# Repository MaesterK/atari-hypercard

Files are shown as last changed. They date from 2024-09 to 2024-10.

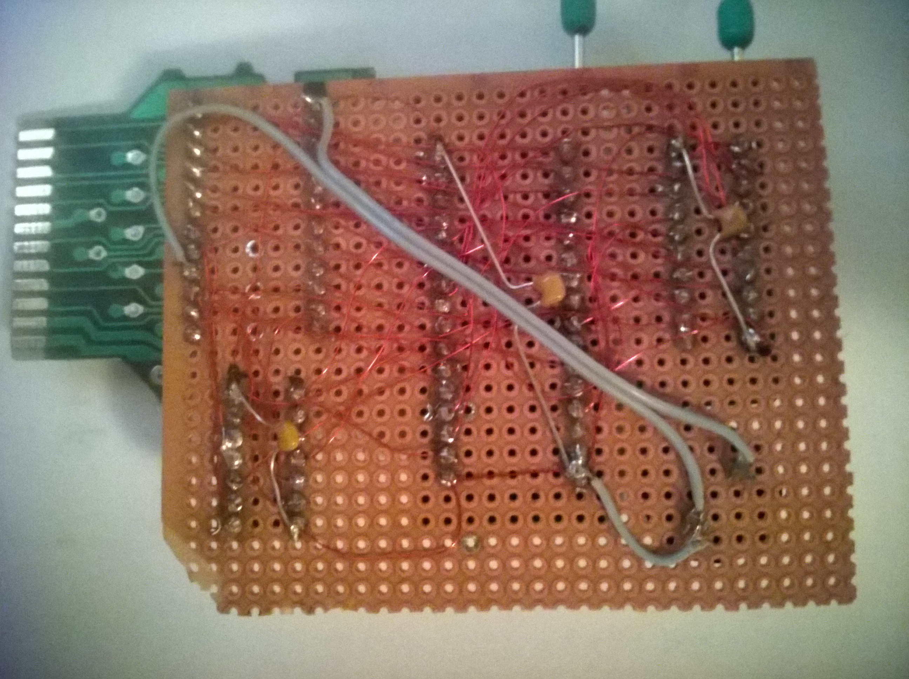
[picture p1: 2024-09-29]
pictures/lochraster_back.jpg

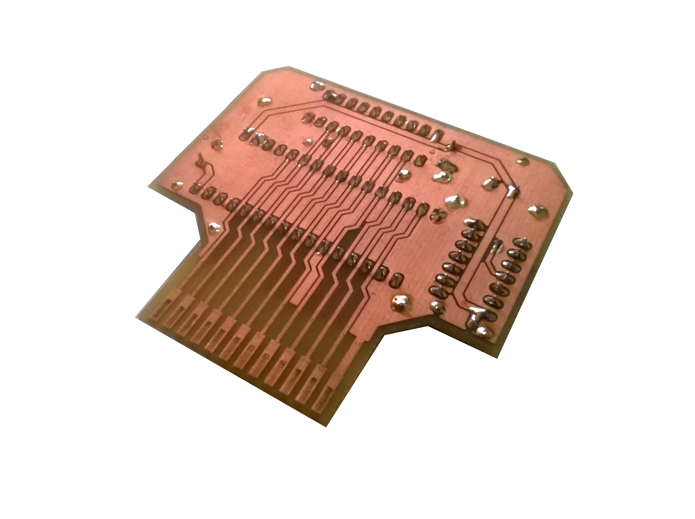
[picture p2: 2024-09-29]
pictures/pcb_rs.png

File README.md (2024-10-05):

Atari VCS / 2600 Supercard with menu implemented for atari itself creating text based menu on the fly.
Uses programmable logic ic (GAL) as latch and nand chip to select and switch between images via adress bus. 
Works only with early ("dumb") images.

The assembly code for the menu build using DASM and the framework (mainly the definitions from vcs.h) from SvOlli's atari 2600 workshop (https://svolli.org/atari2600/)

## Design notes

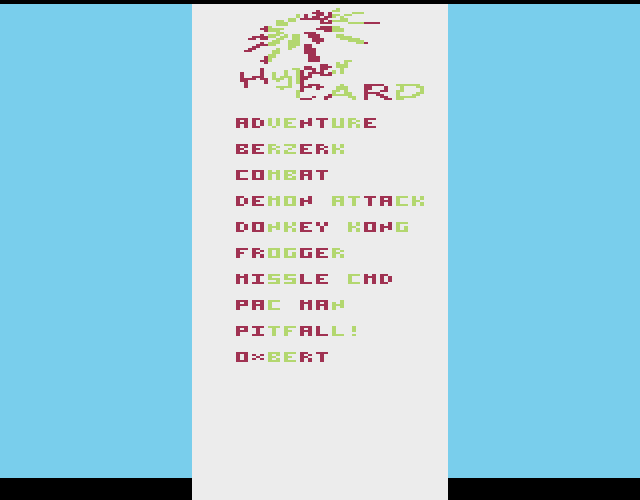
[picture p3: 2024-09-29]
pictures/menue2.png

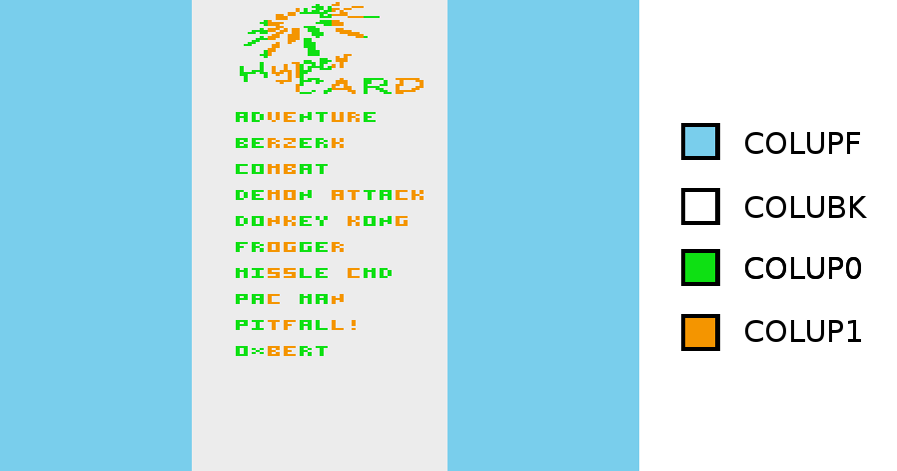
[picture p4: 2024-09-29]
pictures/menueexplained.png

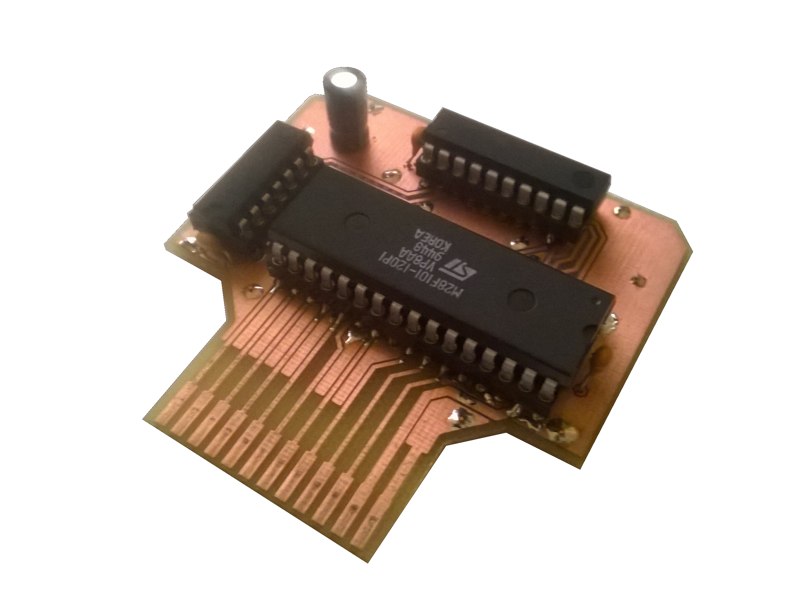
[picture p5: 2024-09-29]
pictures/pcb_vs.png

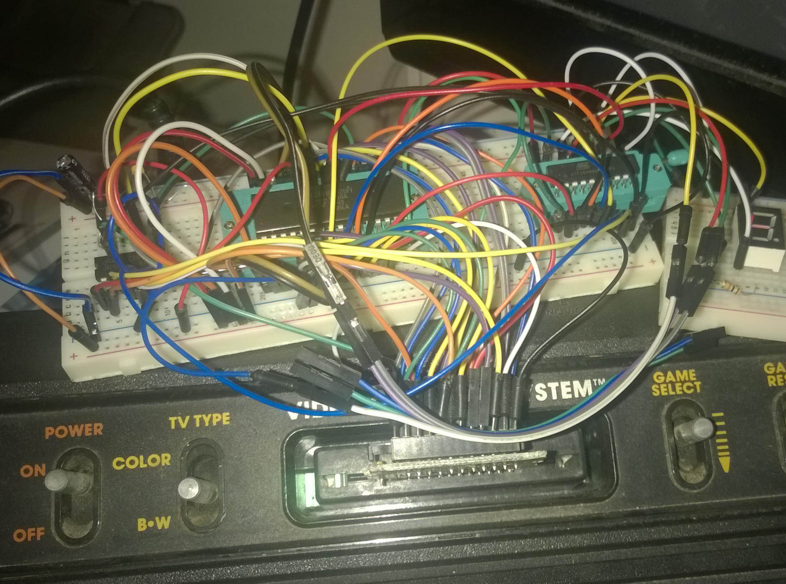
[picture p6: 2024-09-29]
pictures/breadboard_complete_small.jpg

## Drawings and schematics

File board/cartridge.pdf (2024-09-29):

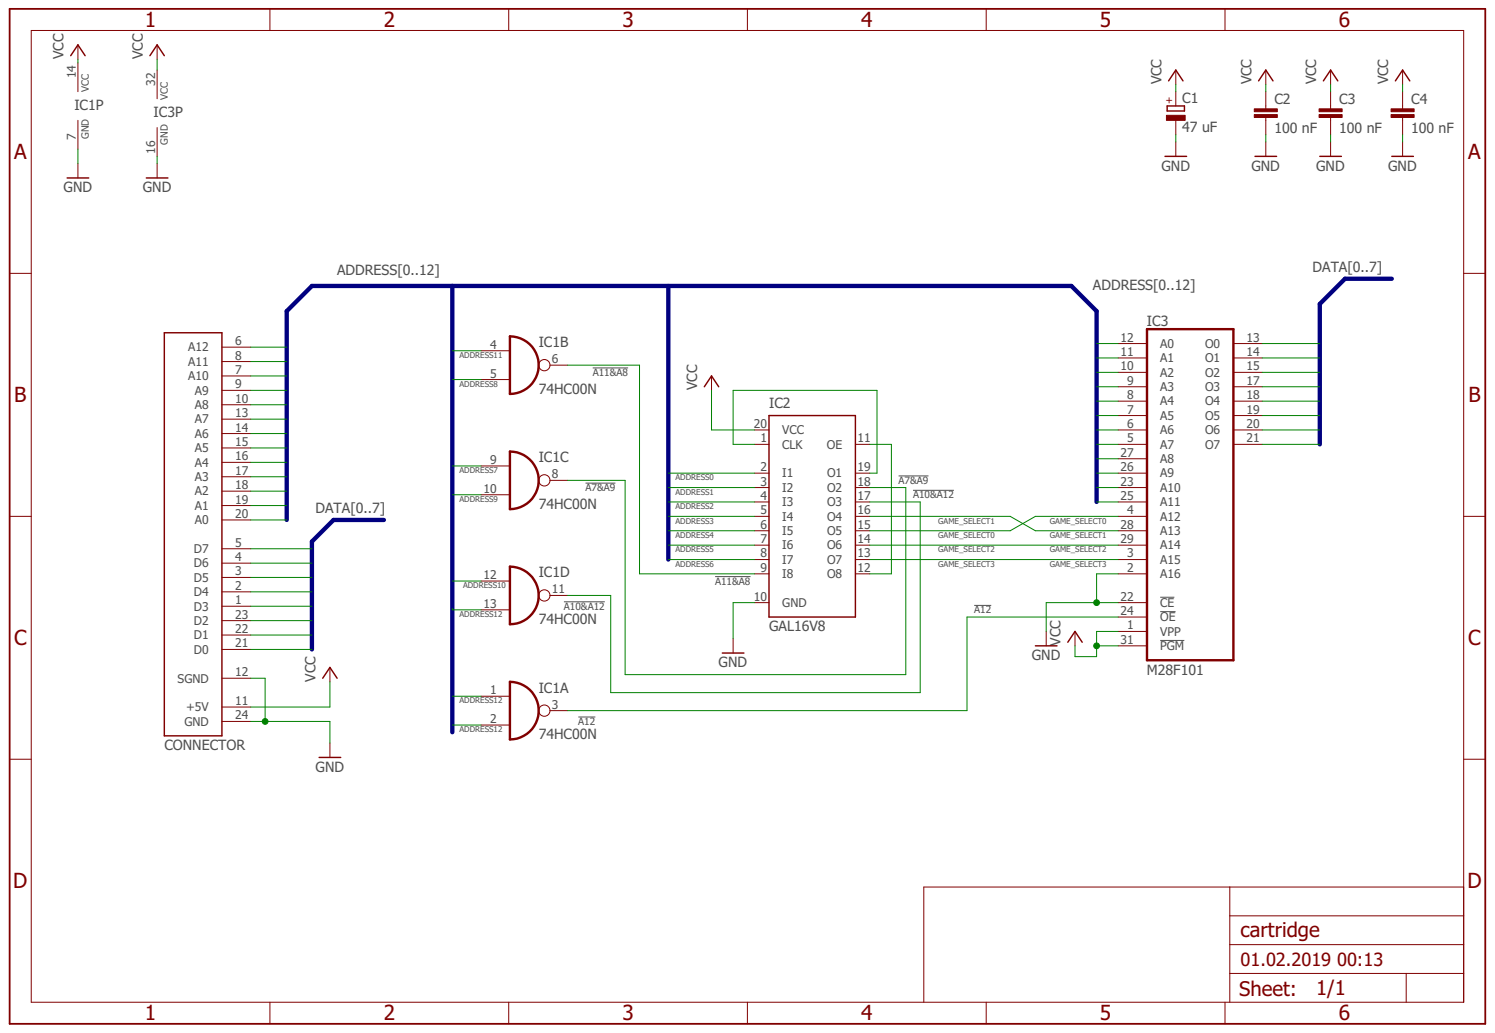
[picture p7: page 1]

IC3P ADDRESS DATA[0..7] [0..12]

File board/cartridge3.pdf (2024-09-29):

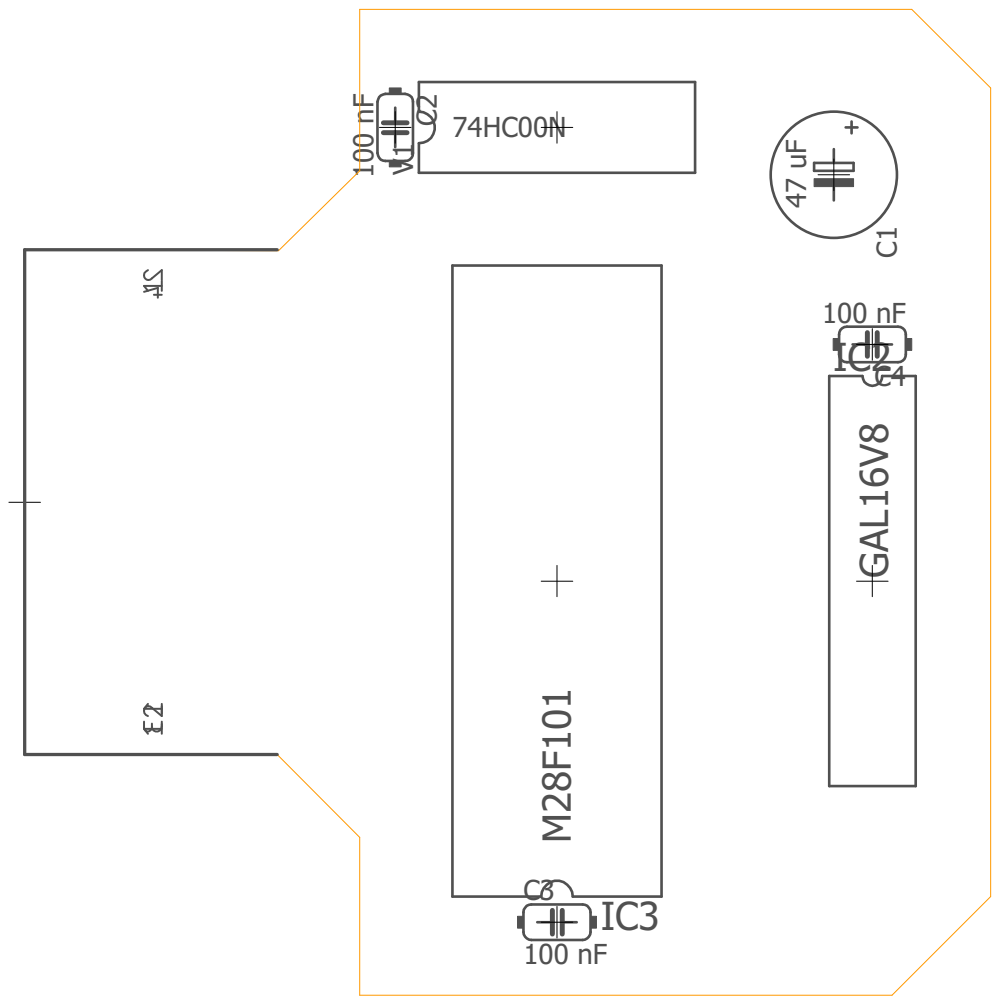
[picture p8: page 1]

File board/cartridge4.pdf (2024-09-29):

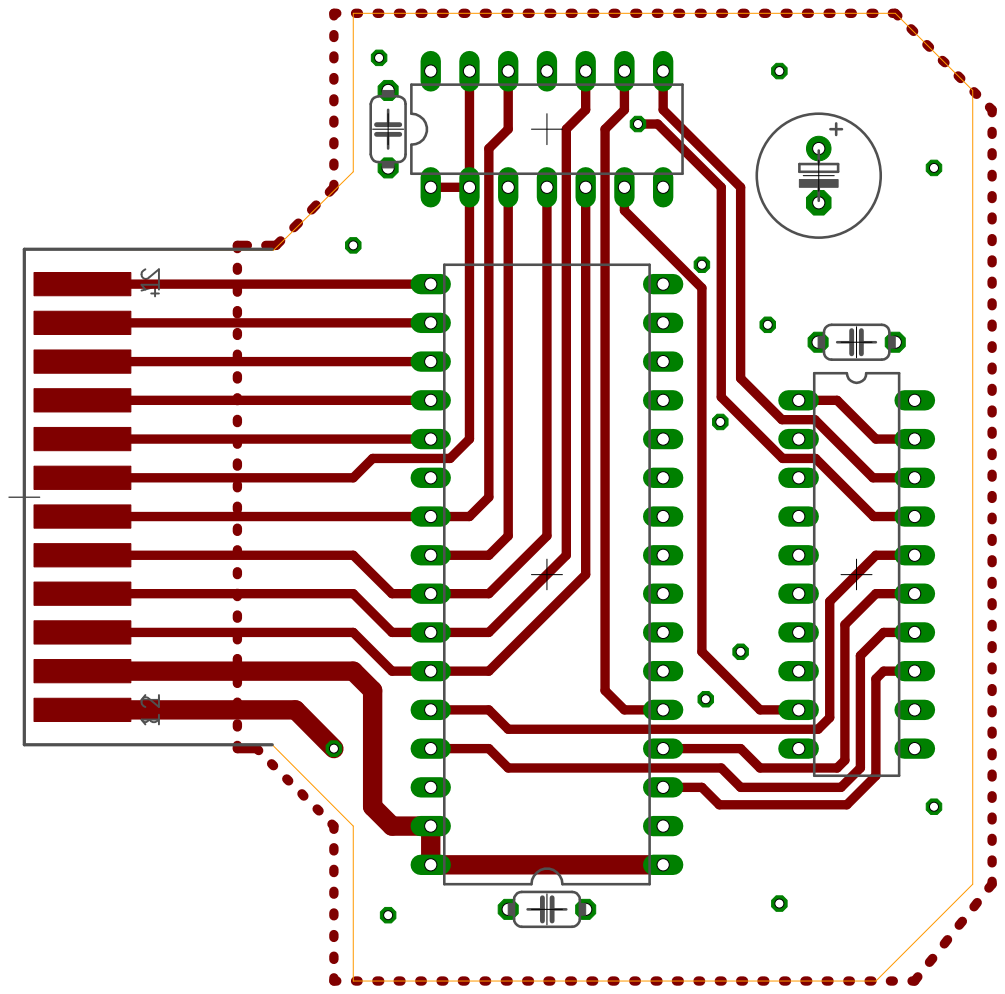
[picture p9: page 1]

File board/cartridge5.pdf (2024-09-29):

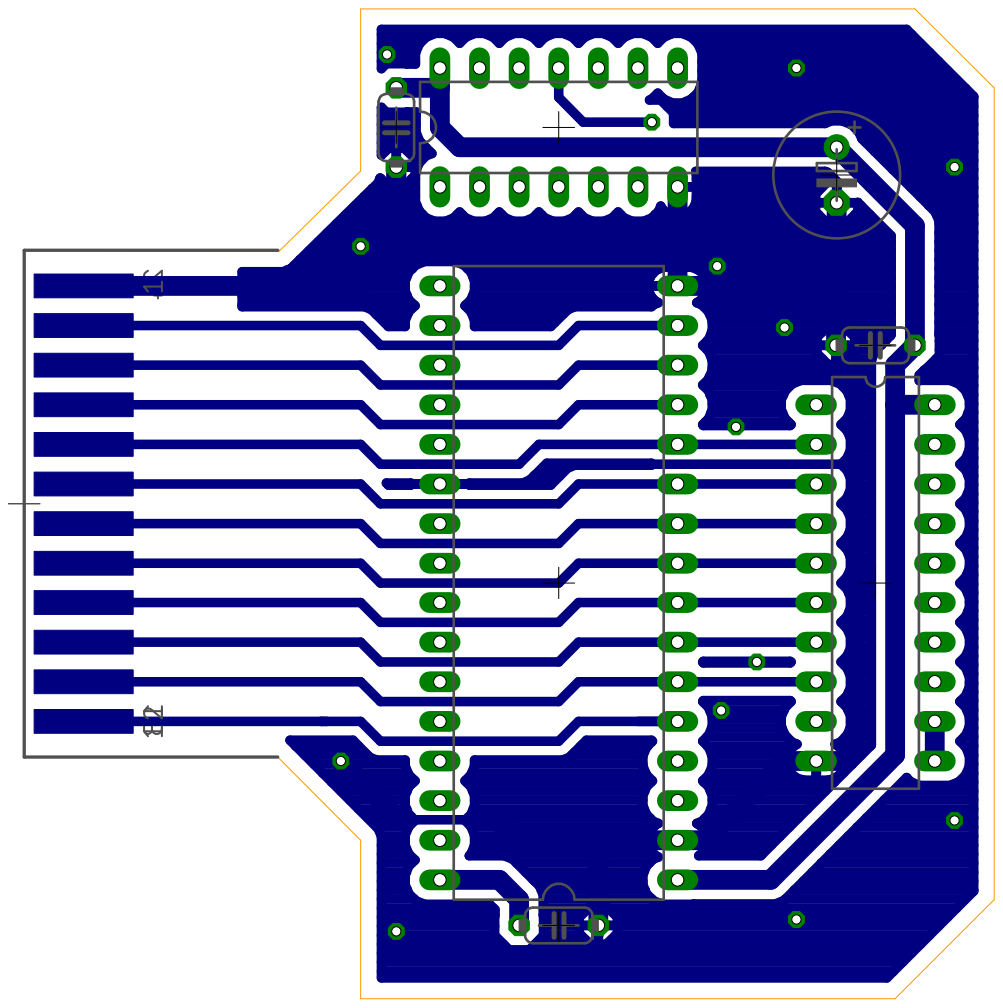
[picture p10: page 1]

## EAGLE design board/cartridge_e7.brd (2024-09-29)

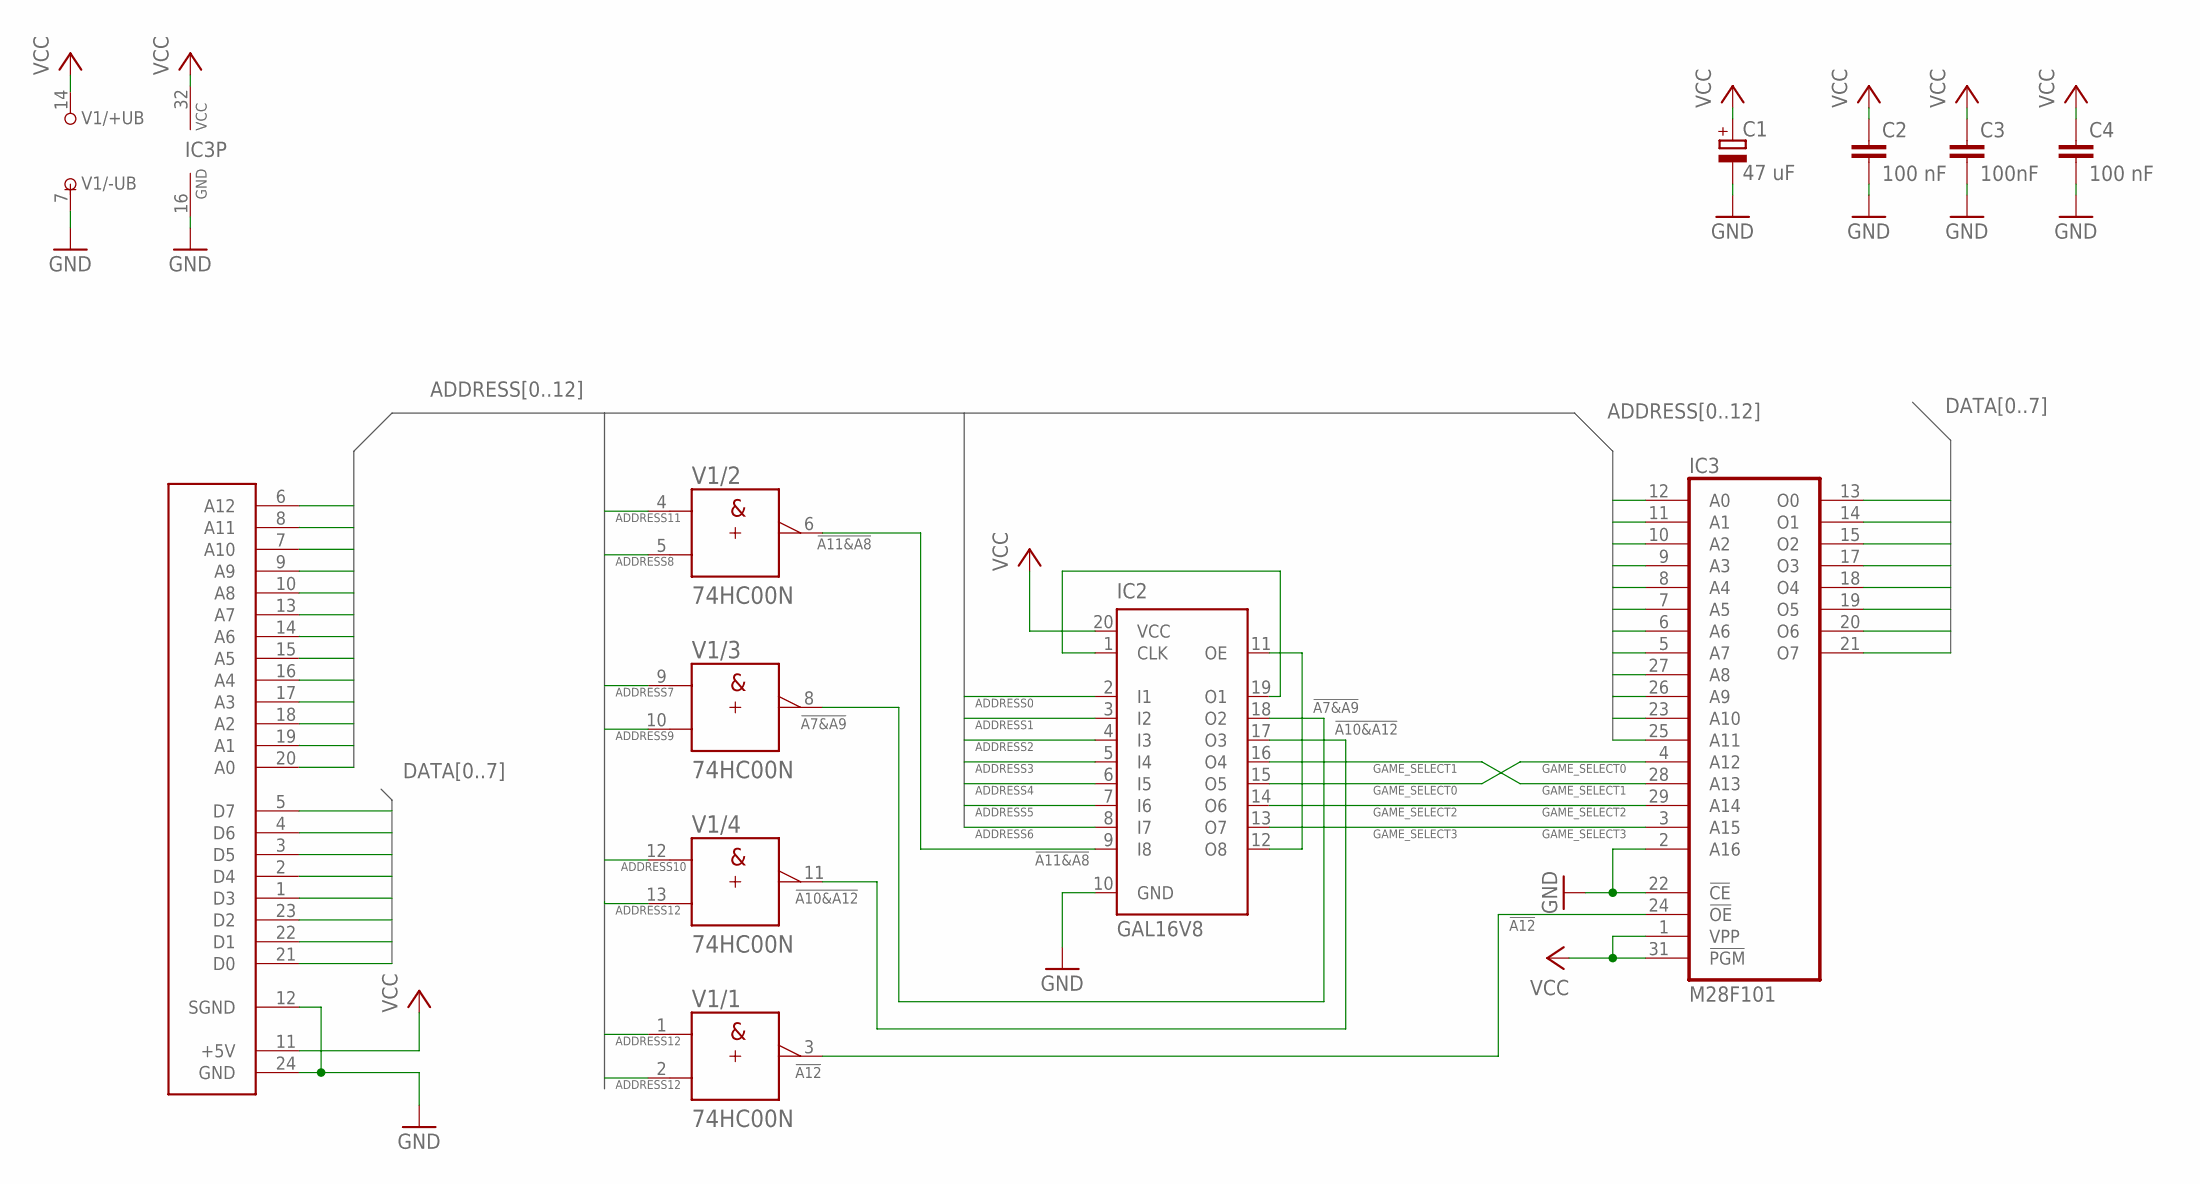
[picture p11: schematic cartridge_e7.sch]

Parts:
C1: 47 uF; E3,5-8
C2, C4: 100 nF; C050-024X044
C3: 100nF; C050-024X044
CONN1: 24POSCELARGE; 2600LARGE
IC2: GAL16V8; DIL20
IC3: M28F101; DIL32
V1: 74HC00N; DIL14

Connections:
!A7&A9: IC2.18 (O2), V1.8 (Y)
!A10&A12: IC2.17 (O3), V1.11 (Y)
!A11&A8: IC2.9 (I8), V1.6 (Y)
!A12: IC3.24 (!OE), V1.3 (Y)
ADDRESS0: CONN1.20 (A0), IC2.2 (I1), IC3.12 (A0)
ADDRESS1: CONN1.19 (A1), IC2.3 (I2), IC3.11 (A1)
ADDRESS2: CONN1.18 (A2), IC2.4 (I3), IC3.10 (A2)
ADDRESS3: CONN1.17 (A3), IC2.5 (I4), IC3.9 (A3)
ADDRESS4: CONN1.16 (A4), IC2.6 (I5), IC3.8 (A4)
ADDRESS5: CONN1.15 (A5), IC2.7 (I6), IC3.7 (A5)
ADDRESS6: CONN1.14 (A6), IC2.8 (I7), IC3.6 (A6)
ADDRESS7: CONN1.13 (A7), IC3.5 (A7), V1.9 (A)
ADDRESS8: CONN1.10 (A8), IC3.27 (A8), V1.5 (B)
ADDRESS9: CONN1.9 (A9), IC3.26 (A9), V1.10 (B)
ADDRESS10: CONN1.7 (A10), IC3.23 (A10), V1.12 (A)
ADDRESS11: CONN1.8 (A11), IC3.25 (A11), V1.4 (A)
ADDRESS12: CONN1.6 (A12), V1.1 (A), V1.2 (B), V1.13 (B)
DATA0: CONN1.21 (D0), IC3.13 (O0)
DATA1: CONN1.22 (D1), IC3.14 (O1)
DATA2: CONN1.23 (D2), IC3.15 (O2)
DATA3: CONN1.1 (D3), IC3.17 (O3)
DATA4: CONN1.2 (D4), IC3.18 (O4)
DATA5: CONN1.3 (D5), IC3.19 (O5)
DATA6: CONN1.4 (D6), IC3.20 (O6)
DATA7: CONN1.5 (D7), IC3.21 (O7)
GAME_SELECT0: IC2.15 (O5), IC3.4 (A12)
GAME_SELECT1: IC2.16 (O4), IC3.28 (A13)
GAME_SELECT2: IC2.14 (O6), IC3.29 (A14)
GAME_SELECT3: IC2.13 (O7), IC3.3 (A15)
GND: C1.-, C2.2, C3.2, C4.2, CONN1.12 (SGND), CONN1.24 (GND), IC2.10 (GND), IC3.2 (A16), IC3.16 (GND), IC3.22 (!CE), V1.7 (-UB)
unnamed: IC2.11 (OE), IC2.12 (O8)
unnamed: IC2.1 (CLK), IC2.19 (O1)
VCC: C1.+, C2.1, C3.1, C4.1, CONN1.11 (+5V), IC2.20 (VCC), IC3.1 (VPP), IC3.31 (!PGM), IC3.32 (VCC), V1.14 (+UB)

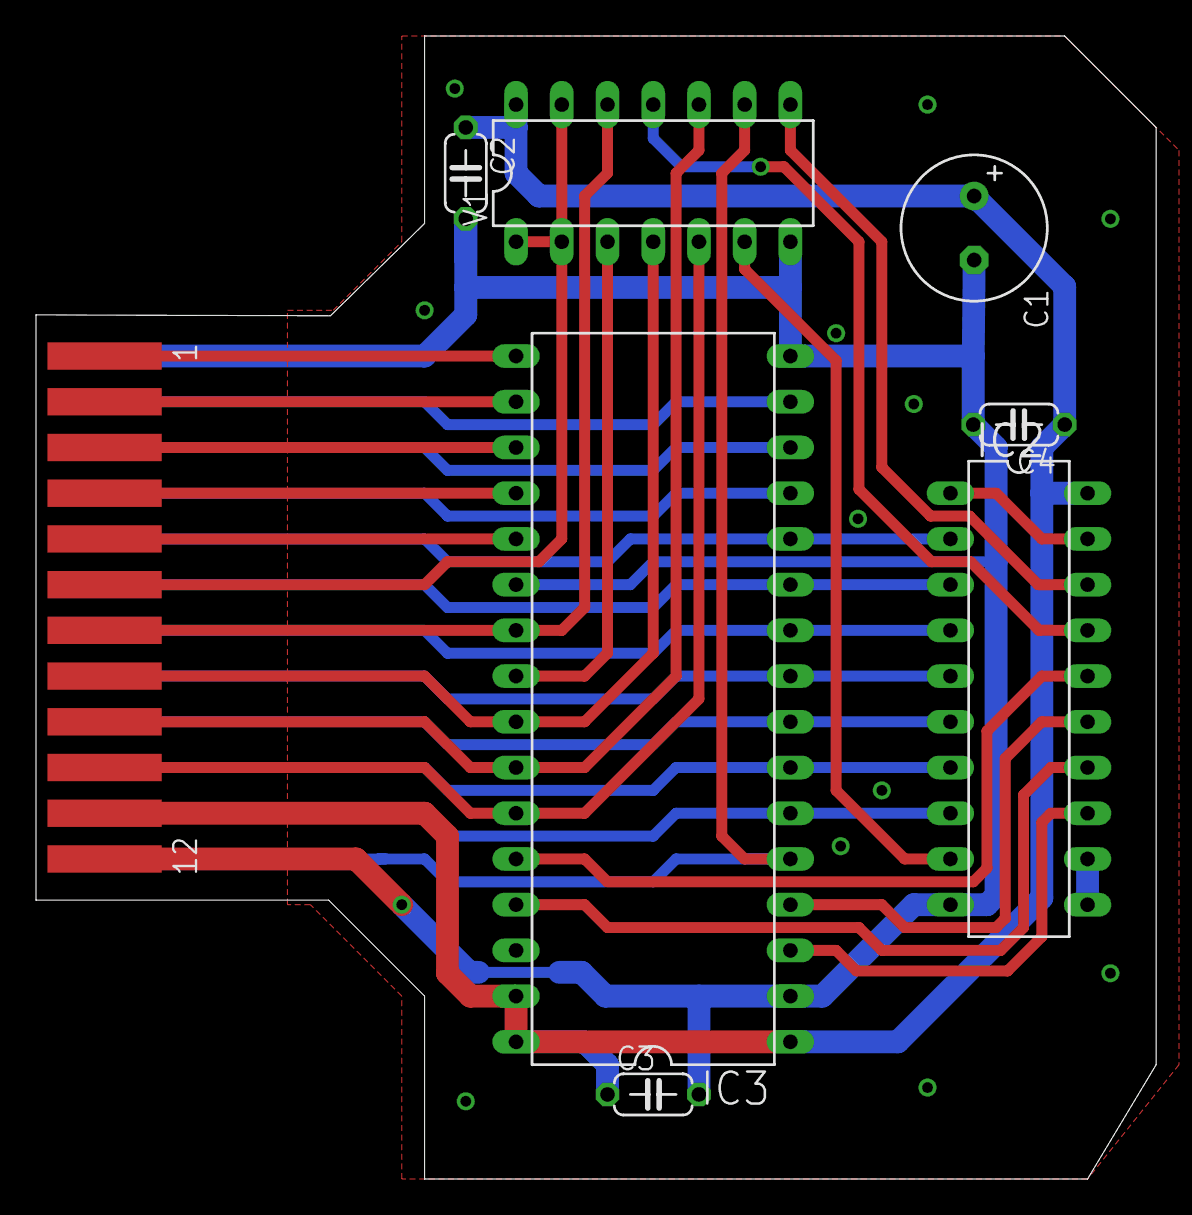
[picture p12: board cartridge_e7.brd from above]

Board: 2 copper layers, 62.2 x 63.5 mm, 8 parts (0 on the bottom side), 33 nets.

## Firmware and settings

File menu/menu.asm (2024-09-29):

        processor 6502
        include vcs.h


;konstanten und variablen

;grafikpufferbereich fuer anzuzeigenden text im ram..wird ueber stackpointer gefuellt
textcol5 equ $80
textcol4 equ $85
textcol3 equ $8a
textcol2 equ $8f
textcol1 equ $94
textcol0 equ $99
textcolz equ $9e ;stackpointer muss auf "eins darueber" liegendes element gesetzt werden


xbuff equ $a0
ybuff equ $a1
abuff equ $a2
curseltextindex  equ $a3
curselindex equ $a4
gameselection_low equ $a5
gameselection_high equ $a6
textline equ $a7
spbuff equ $a8
; equ $a9
tempx equ $aa
grafbuff equ $ab
curtextpos equ $ac
curstackpos equ $ad
lastiostate equ $ae
starttextline equ $af

lowerascii0 equ lowerfont0-32 ;TODO so machen statt mit dem aktuellen gewurschtel!
GAMECOUNT equ 15
GAMEVIEWCOUNT equ 8

;geklautes sleep-makro
  MAC SLEEP
    IF {1} = 1
      ECHO "ERROR: SLEEP 1 not allowed !"
      END
    ENDIF
    IF {1} & 1
      nop $00
      REPEAT ({1}-3)/2
        nop
      REPEND
    ELSE
      REPEAT ({1})/2
        nop
      REPEND
    ENDIF
  ENDM

;makro zum speicher und register initialiseren..stellt ausserdem sicher dass interrupts und dezimal-modus aus sind
	MAC INITSYSTEM
	sei ;interrupts aus (disable an)
    cld ; bcd-modus aus
	
	;register alle auf null
	lda #0
	tay
	tax
	;.. und dann durch tia und ram (0000-00ff) iterieren und alles auf 0 setzen
.clear
	sta 0,x
	inx
	bne .clear
	ENDM



;beginn programm
    org $F000


Start

	INITSYSTEM ;sichere arbeitsverhaeltnisse herstellen

;variablen und register initialisieren

		lda <#gameselectionarea ;unteres byte adresse selektionsbereich
		sta gameselection_low
		lda >#gameselectionarea ;oberes byte selektionsbereich
		sta gameselection_high
		
        lda #$9C
		sta COLUBK
		lda #$00
        sta COLUP0
 ;       lda #$99
        sta COLUP1
        lda #255
        sta PF0
        sta PF1
        lda #0
        sta PF2
		sta starttextline

		sta curseltextindex
		sta curselindex
		;joystickports als output
		sta SWACNT
		lda #$FF
		sta lastiostate
		
        lda #%00000101
		
		
        sta WSYNC ;3c
		
		;hier beginnt eine neue Zeile bei 0c
		;1 cpu-zyklus = 1c = 3 pixel!
		
        sta CTRLPF ;3c spielfeldkonfiguration
		
		
        sta GRP0 ;3c
        sta GRP1 ;3c
		
		;spritemodi auf 3fach mit geringem abstand schalten
        lda #$03  ;2c         
        sta NUSIZ0 ;3c
        sta NUSIZ1 ;3c
		
		;vertikal delay fuer ausgabelatch sprites aktivieren
        lda #$01     ;      
        sta VDELP0		
        sta $2d 
        sta VDELP1		
		
		;8 cyclen warrten fuer positionierung
		nop ;2c
		nop ;2c
		nop ;2c
		nop ;2c
		
		;hier position 37 cpu-zyklen, damit pixelpos 37*3 -68 hblank = 43
	
		;spritepos setzen;player0 pixelpos 5 bzw player1 8px rechts ddavon
        sta.w RESP0 ;3c
        sta RESP1 ;3c
		;positionskorrektur ueber move-register
        lda #%11110000 ;2c -2 => player0 zwei pixel nach rechts
        sta HMP1 ;3c
        lda #%11100000 ;2c -1 => player1 einen pixel nach links
        sta HMP0 ;3c

        sta WSYNC ;3c
		;!! hmove muss (soll) direkt nach wsync ausgefuehrt werden!!
        sta HMOVE;3c versatz er sprites aus HMPx-regs uebernehmen



GameLoop
        jsr VSync       ;start vertical retrace

        jsr VBlank      ; spare time during screen blank
        jsr Picture     ; draw one screen
        jsr overscan    ; do overscan

        jmp GameLoop    ;back to top


VSync
        lda #2          ;bit 1 needs to be 1 to start retrace
        sta VSYNC       ;start retrace
        sta WSYNC       ;wait a few lines
        sta WSYNC
        lda #44         ;prepare timer to exit blank period (44)
        sta TIM64T      ;turn it on
        sta WSYNC       ;wait one more
        sta VSYNC       ;done with retrace, write 0 to bit 1

        rts ; VSync



VBlank

        rts ; VBlank




overscan

        sta WSYNC

        lda #$0E
        sta COLUBK

        lda #36         ; Use the timer to make sure overscan takes (34)
        sta TIM64T      ; 30 scan lines.  29 scan lines * 76 = 2204 / 64 = 34.4

; hier ist platz um bissl was zu tun...solange es weniger als die oben erwaehnten 34 clockcycles sind		

;eingabe von joystick abfragen
;dabei nur auf flanke reagieren
		lda lastiostate
		eor SWCHA
		beq noiochanged
		
		;aktuelle eingabe laden
		lda SWCHA
		;..und fuer vergleich bei naechstem durchlauf sichern
		sta lastiostate
		
		lda #%00100000;runter
		bit SWCHA
		bne ionotdown
		
		;einhaltung der grenze checken
		ldy curselindex
		iny
		cpy #GAMECOUNT
		beq ionotdown
		
		sty curselindex
		lda curseltextindex
		clc  ;carry flag vor addition loeschen!
		adc #12
		sta curseltextindex	

		;ggf startposition verschieben
		cpy #5
		bcc ionotdown
		cpy #GAMECOUNT-#3
		bcs ionotdown
		
		lda starttextline
		clc
		adc #12
		sta starttextline
		
ionotdown

		lda #%00010000;hoch
		bit SWCHA
		bne ionotup
		
		ldy curselindex
		dey
		bmi ionotup;neuen wert nur uebernehmen falls kein ueberlauf		
		sty curselindex
		lda curseltextindex
		;textindex auch updaten
		sec  ;carry flag vor subtraktion setzen!
		sbc #12
		sta curseltextindex

		;ggf startposition verschieben
		cpy #4
		bcc ionotup
		cpy #GAMECOUNT-#3-#1
		bcs ionotup
		
		lda starttextline
		sec
		sbc #12
		sta starttextline

		
ionotup
noiochanged

;bei "fire" ausgewaehltes rom starten
	lda INPT4
	bmi nofire ;bmi prueft vorzeichen == vorderstes bit ==7. bit
	;lda #$10
	;sta COLUBK
	lda gameselection_low
	clc ;carry flag for additon loeschen!
	adc curselindex
	sta gameselection_low
	ldy curselindex
	lda gameselectionarea,y
	jmp restarttoselection
	
nofire



		
endOS
        lda INTIM       ; We finished, but wait for timer
        bne endOS       ; by looping till zero

        sta WSYNC       ; End last scanline

        lda #$82
        sta VBLANK
        lda #$02
        sta VBLANK

        rts     ; overscan





Picture
	ldx #$9C
	stx COLUP0
	stx COLUP1
;warten, bis VBLANK zeitspanne vorbei ist (timer gesetzt)
pictureLoop
        lda INTIM       
        bne pictureLoop 

        sta WSYNC
        lda #$80
        sta VBLANK      ;vblank beenden
		

        lda #$9C
        sta COLUPF

        lda #0



        tsx
        stx spbuff
        
        SLEEP 46


        jsr showImage        
		;lda #0
		lda starttextline
		sta textline
		
		
		ldx #0
printline
		jsr printText
		inx
		cpx #GAMEVIEWCOUNT
		bne printline

		
        lda #0
        sta GRP0
        sta GRP1
        sta GRP0
        sta GRP1


; restore stack pointer

        ldx spbuff
        txs


        ldx #11

ScanLoop
        sta WSYNC
        dex
        bne ScanLoop

        sta COLUPF

        rts     ; Picture




	align 256
showImage

;zeilenweise bild ausgeben
        
		ldx #$30;2c  zaheler fuer zeilenposition
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

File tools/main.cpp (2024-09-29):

#include <iostream>

/* run this program using the console pauser or add your own getch, system("pause") or input loop */


const unsigned char font[96][3] = {
	{0x00,0x00,0x00}, //  
	{0x00,0x2e,0x00}, // !
	{0x06,0x00,0x06}, // "
	{0x3e,0x14,0x3e}, // #
	{0x0c,0x36,0x18}, // $
	{0x32,0x08,0x26}, // %
	{0x14,0x2a,0x34}, // &
	{0x00,0x06,0x00}, // '
	{0x00,0x1c,0x22}, // (
	{0x22,0x1c,0x00}, // )
	{0x14,0x08,0x14}, // *
	{0x08,0x1c,0x08}, // +
	{0x40,0x60,0x00}, // ,
	{0x08,0x08,0x08}, // -
	{0x00,0x20,0x00}, // .
	{0x60,0x1c,0x02}, // /
	{0x3e,0x22,0x3e}, // 0
	{0x24,0x3e,0x20}, // 1
	{0x32,0x2a,0x26}, // 2
	{0x22,0x2a,0x3e}, // 3
	{0x0e,0x08,0x3e}, // 4
	{0x2e,0x2a,0x3a}, // 5
	{0x3e,0x2a,0x3a}, // 6
	{0x02,0x3a,0x06}, // 7
	{0x3e,0x2a,0x3e}, // 8
	{0x2e,0x2a,0x3e}, // 9
	{0x00,0x14,0x00}, // :
	{0x40,0x64,0x00}, // ;
	{0x08,0x14,0x22}, // <
	{0x14,0x14,0x14}, // =
	{0x22,0x14,0x08}, // >
	{0x02,0x2a,0x06}, // ?
	{0x3e,0x22,0x2e}, // @
	{0x3e,0x0a,0x3e}, // A
	{0x3e,0x2a,0x36}, // B
	{0x3e,0x22,0x22}, // C
	{0x3e,0x22,0x1c}, // D
	{0x3e,0x2a,0x22}, // E
	{0x3e,0x0a,0x02}, // F
	{0x3e,0x22,0x3a}, // G
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
};

unsigned char lowerfont[5]['Z'-' ']={};


int main(int argc, char** argv) {
//	int ci=33;//33=A

		for (int i=1;i<6;i++){
	for(int ci=0;ci<=('Z'-' ');ci++){			
		char curbyte=0;
		for(int j=0;j<3;j++){
			curbyte|=((font[ci][j]&1<<(i))?1:0)<<(3-j);
	//		printf("%c",(font[ci][j]&1<<(i))? '0':' ');
			
		}
		lowerfont[i-1][ci]=curbyte;
		printf(" ");
		
	}printf("\n");
	}

for(int i=0;i<5;i++){
	for(int j=0;j<7;j++){
		for(int k=0;k<8;k++){
			printf(((lowerfont[i][j]>>(7-k))&1) ? "*" : " ");	
			}
	//	printf("%c",(upperfont[i][j]&1<<(i))? '0':' ');
	}printf("\n");
}

for(int i=0;i<5;i++){
	printf("lowerfont%i\n",i);
	for(int j=0;j<=('Z'-' ');j++){

		printf("\tbyte $%02x\n",lowerfont[i][j]);	
			
	//	printf("%c",(upperfont[i][j]&1<<(i))? '0':' ');
	}printf("\n");
}
for(int i=0;i<5;i++){
	printf("upperfont%i\n",i);
	for(int j=0;j<=('Z'-' ');j++){

		printf("\tbyte $%02x\n",lowerfont[i][j]<<4);	
			
	//	printf("%c",(upperfont[i][j]&1<<(i))? '0':' ');
	}printf("\n");
}


	
	return 0;
}
